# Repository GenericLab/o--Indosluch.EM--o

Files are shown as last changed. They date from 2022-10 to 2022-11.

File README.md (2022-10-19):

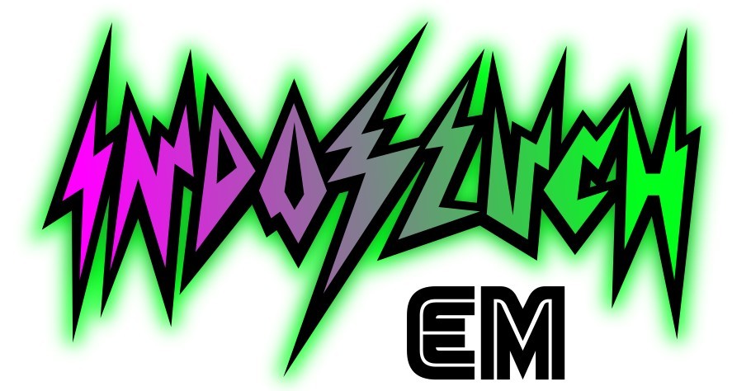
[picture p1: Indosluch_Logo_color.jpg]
IndoSluch Logo by Helmi


# o--Indosluch.EM--o
New pisibi and circuit for EM-sniffer, inspired by LOM's Elektrosluch (Error Static Zapper too), SOMA Ether, 1010 Detektor and Franzis' Bat-Detector and many others...

Goal: Make an affordable new and kinda modified / improved version of an EM sniffer in Yoygakarta, Indonesia. Use mainly parts that can be sourced locally on the common online shops or local stores.

Ideas:
* runs on 3V, LiPo, USB charging and / or powerbank
* single input / mono (mbe switched plug, to insert self-made antennas/coils)
* internal small speaker
* Volume knob
* Frequency shifting / demoluation of higher bandwidths to the audio range (with a knob to select bands)
* output mini-jack, 3.5mm
* beautifully crafted local teakwood casing
* ...

# Collaborators
* dusjagr
* Fiky
* Ucok

## Counselors
* Uwe, the Opa Master
* Ralf, another Opa Master

# Case study and mock-ups

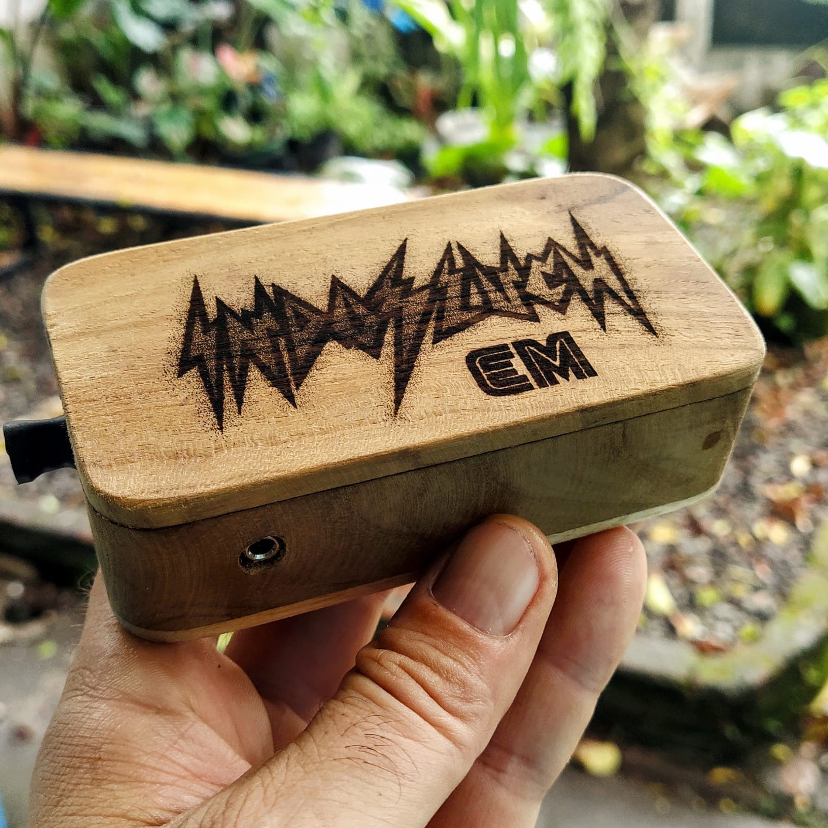
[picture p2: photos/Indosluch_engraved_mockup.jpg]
IndoSluch Logo by Helmi


# Reworking the Bat-Detector

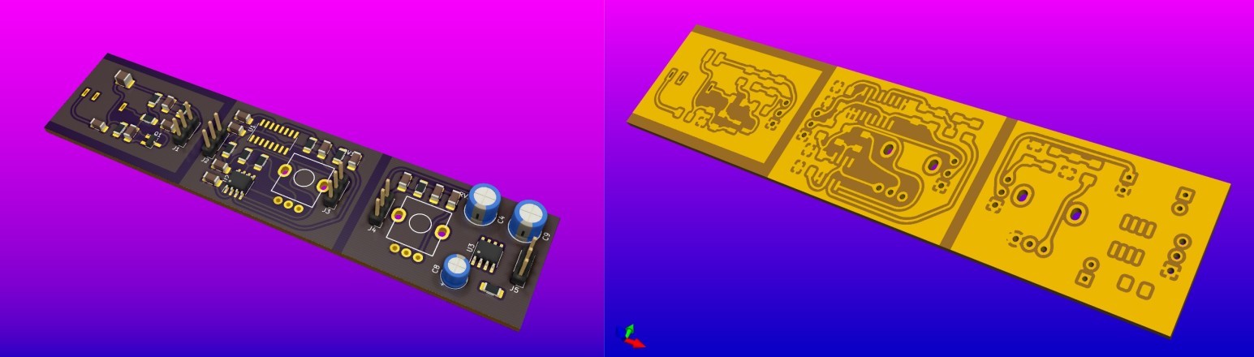
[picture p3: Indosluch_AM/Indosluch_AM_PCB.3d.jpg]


Kicad version of the Fledermaus Detektor (bat-detector): https://www.elektronik-labor.de/Lernpakete/Fledermaus.html

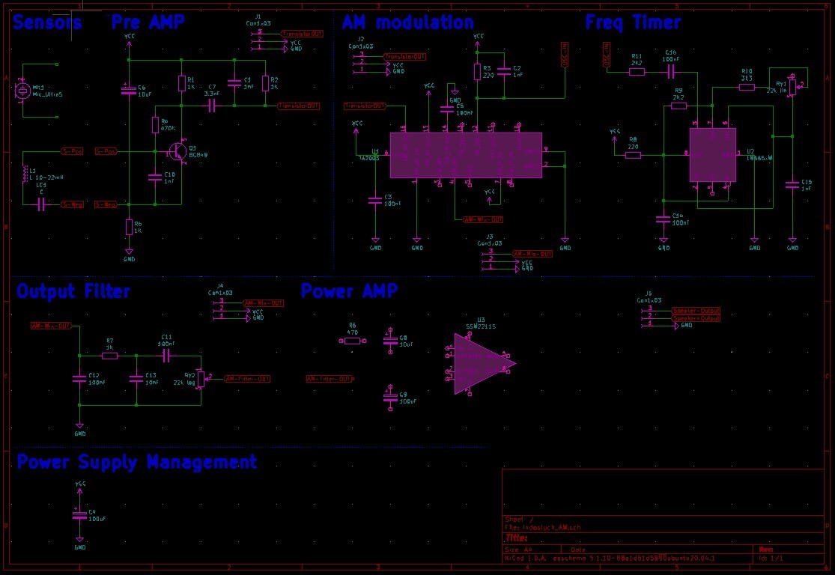
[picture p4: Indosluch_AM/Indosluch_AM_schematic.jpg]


# Inspriational Sources

## LOM's Elektrosluch (open Source)

Based on a single chip dual channel bi-polar Audio Operational Amplifier, opa1612, can be replaced by cheaper more noisier TL074  (suchas the Error Zapper). Runs on 9V. 

https://github.com/LOM-instruments/Elektrosluch-3-plus

## ERROR Zapper

Seems to be a clone, cheaper version of the Elektrosluch. No credits given :-(
Runs on 9V.

https://www.errorinstruments.com/a-60734445/new-synthe-noise-instruments-for-sale/error-zapper/#description

## SOMA Ether (everything is waves)

Based on a fist stage transistor amplification, and some kinda extra antenna on the board for higher frequency bands and a potentiomter for atenuation. Second stage with SSM2211 audio amplifier. Runs on 3V.

https://somasynths.com/ether/

## 1010 Detektor by Martin Howse (open Source)

Based on AD8313 HF-detektor (kinda expensive) and fist stage amplification with LM358, second LM386. Runs on 4.5V.

http://www.1010.co.uk/org/detektor.html

## Elektronik-Labor |  Bat-Detector (open Source) in german

Based on a first stage single transistor amplification, and a radio AM/FM chip CD2003 for high-frequency demodulation, frequency is adjusted with 555 timer. Final amplification stage with LM386. Original design runs on 9V, but lower voltage should work.

https://www.elektronik-labor.de/Lernpakete/Fledermaus.html

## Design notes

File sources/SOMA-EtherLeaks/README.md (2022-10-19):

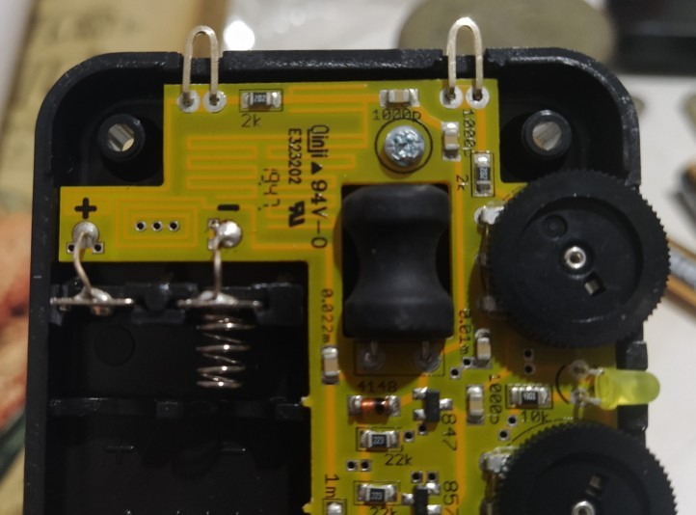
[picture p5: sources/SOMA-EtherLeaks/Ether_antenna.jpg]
Inside the SOMA Ether


# Ether-Leaks

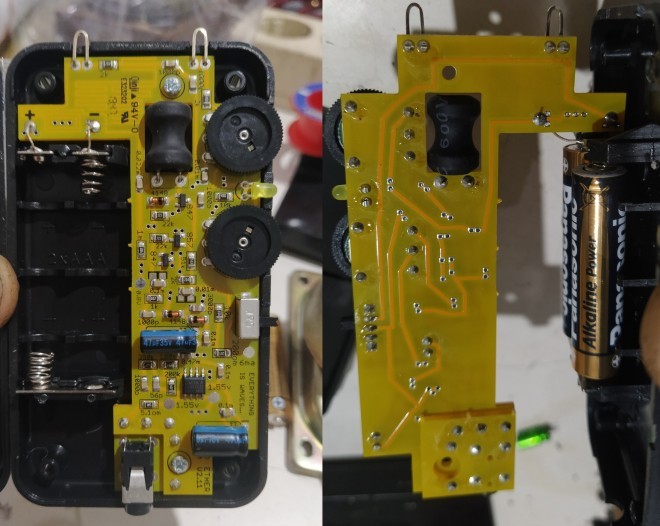
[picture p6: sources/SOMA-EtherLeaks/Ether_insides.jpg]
Inside the SOMA Ether


## SOMA Ether (everything is waves)

Based on a fist stage transistor amplification, and some kinda extra antenna on the board for higher frequency bands and a potentiomter for atenuation. Second stage with SSM2211 audio amplifier. Runs on 3V.

https://somasynths.com/ether/

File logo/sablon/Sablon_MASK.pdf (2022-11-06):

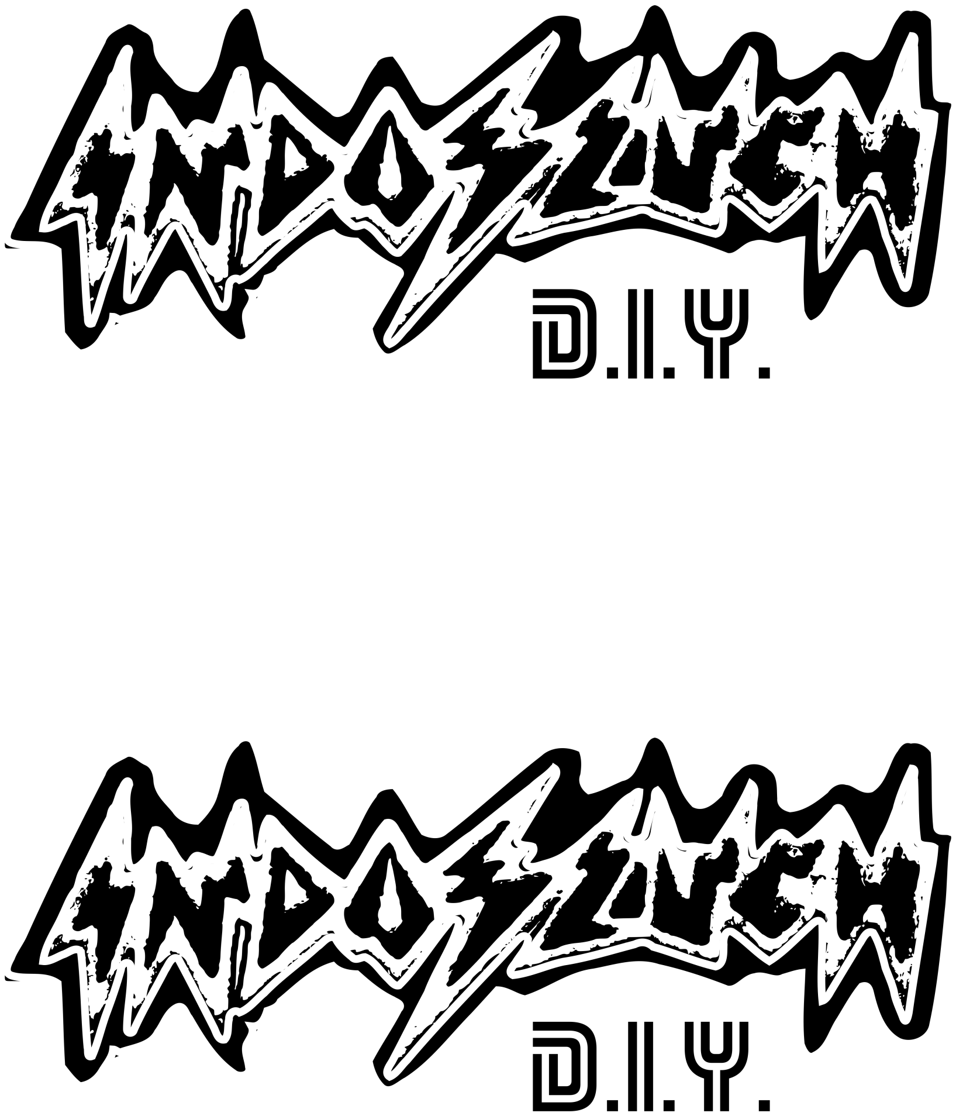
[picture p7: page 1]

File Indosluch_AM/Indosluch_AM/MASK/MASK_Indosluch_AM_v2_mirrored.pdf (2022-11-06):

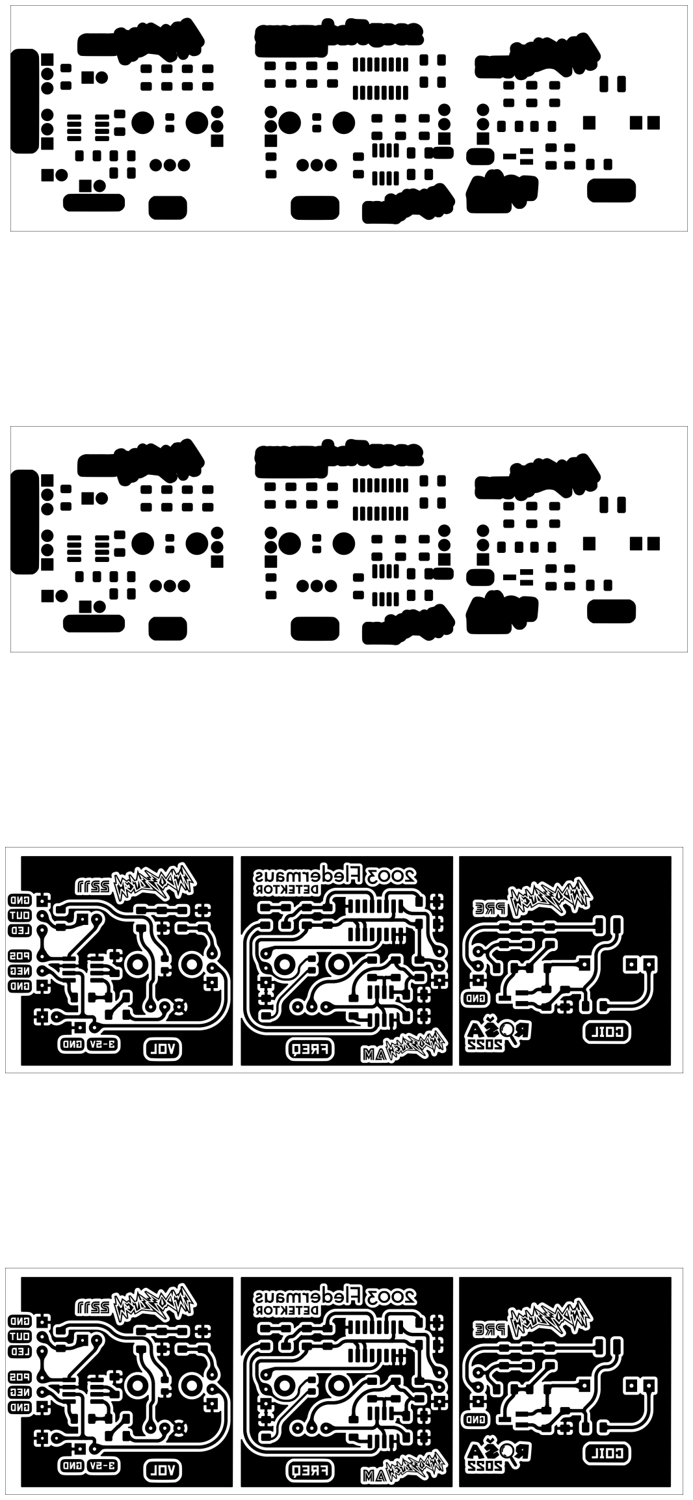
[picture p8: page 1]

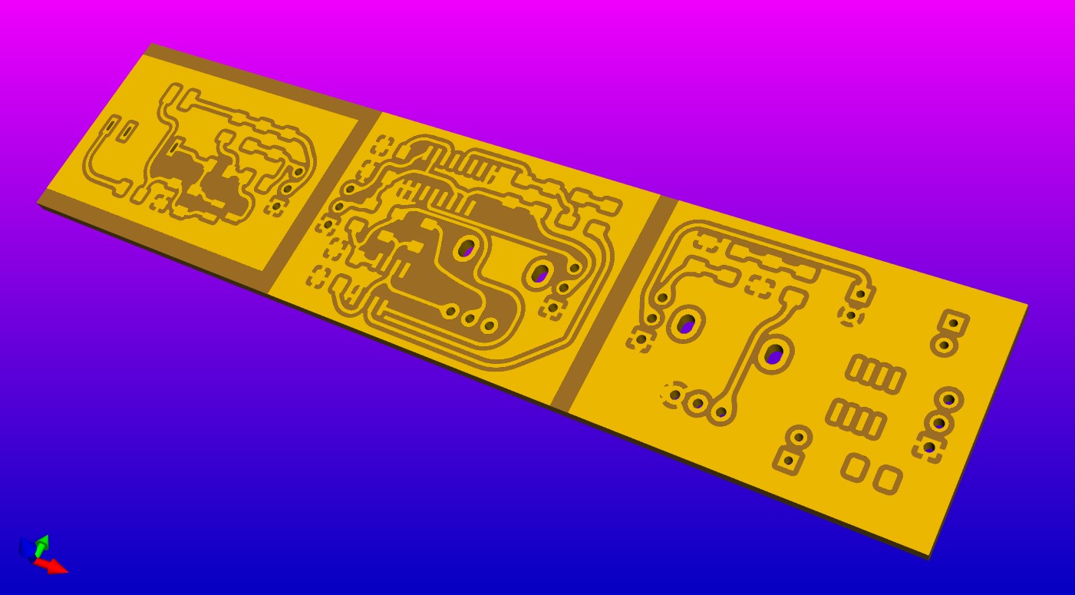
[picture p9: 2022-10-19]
photos/Indosluch_AM_copper.jpg

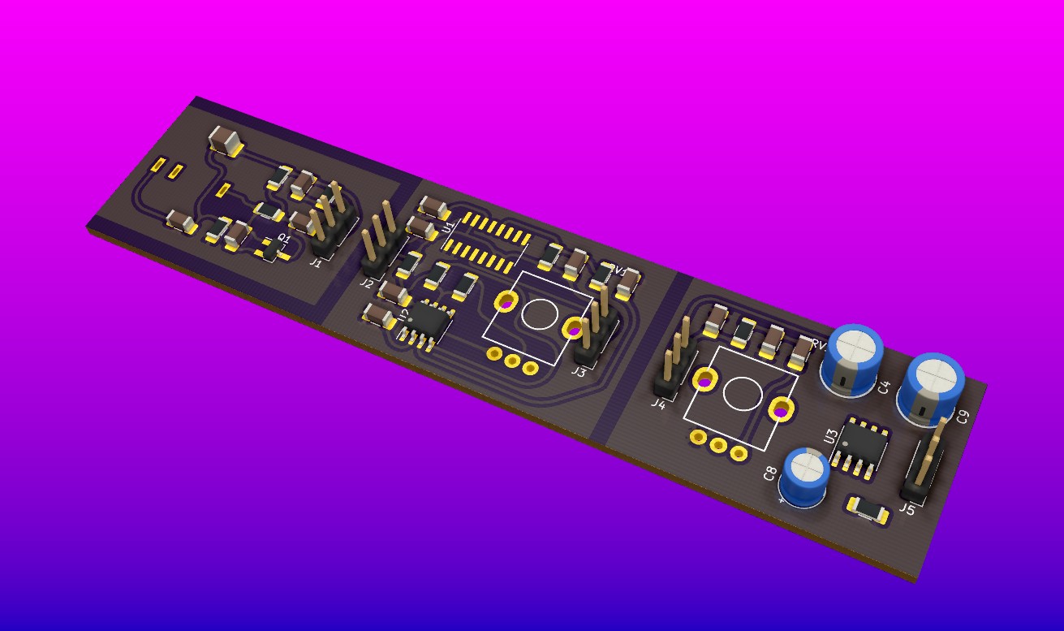
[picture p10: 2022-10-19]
photos/Indosluch_AM_3D.jpg

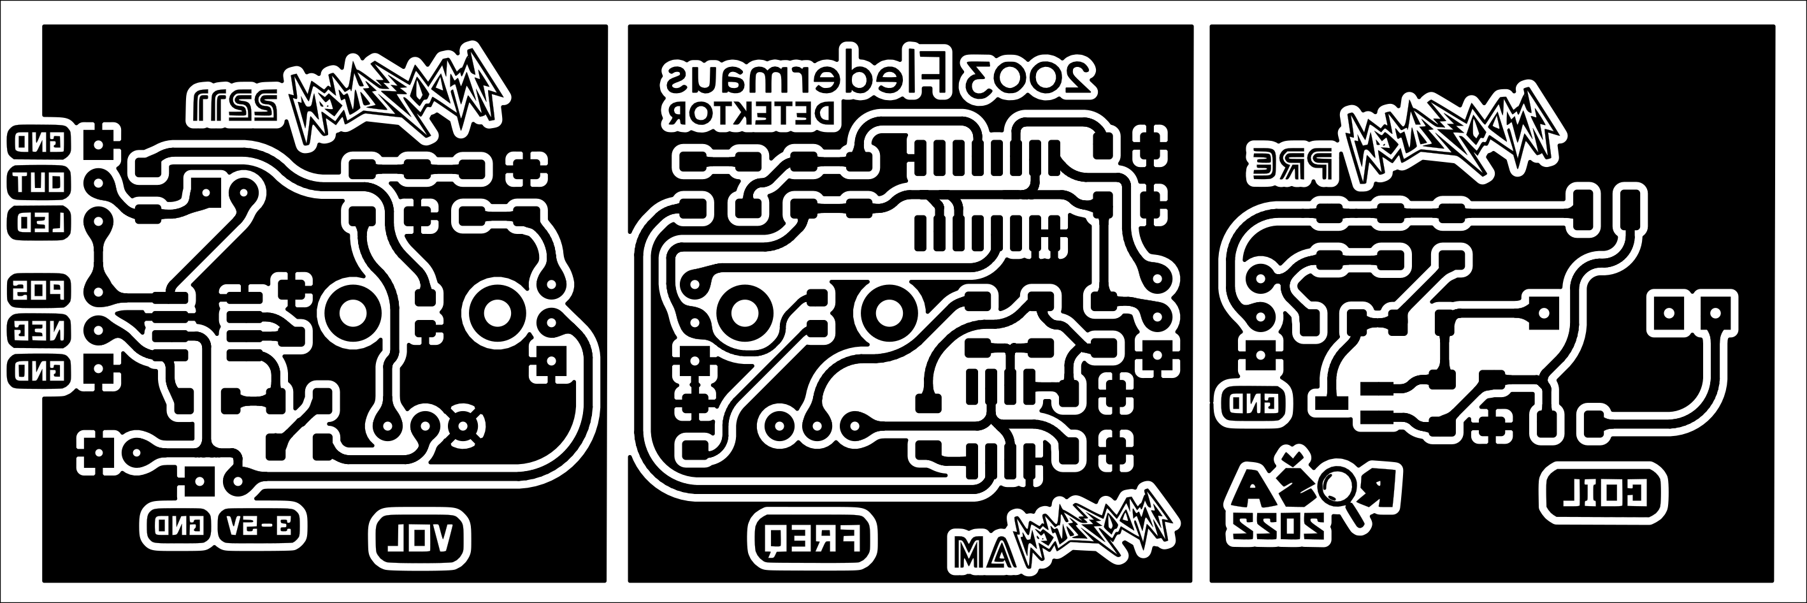
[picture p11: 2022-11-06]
Indosluch_AM/Indosluch_AM/MASK/FrontMask.png

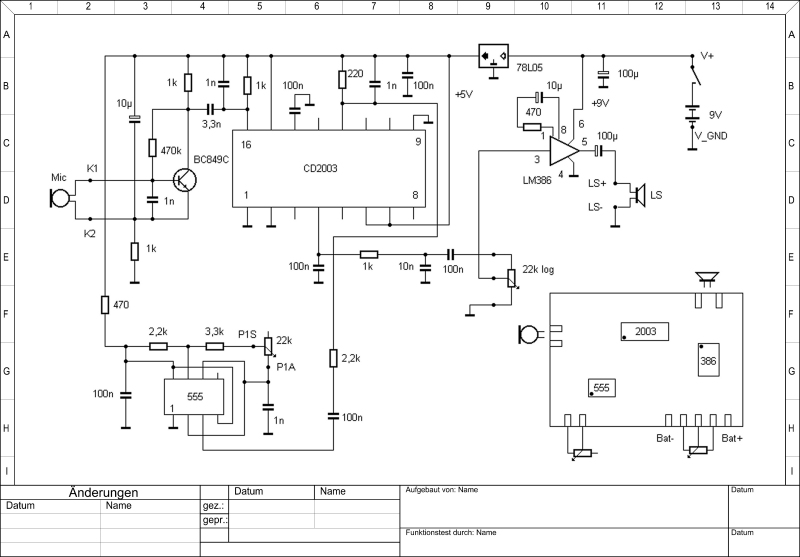
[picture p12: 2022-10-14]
sources/Franzis_Bat-Detector/CD2003_Bat-Detector.jpg

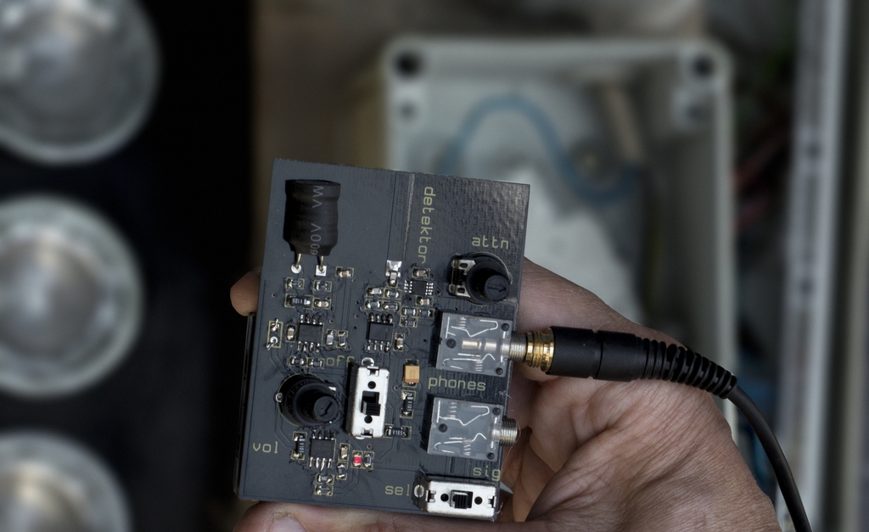
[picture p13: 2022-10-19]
sources/MartinHowse_Detektor/Detektor_finalBoard.jpg

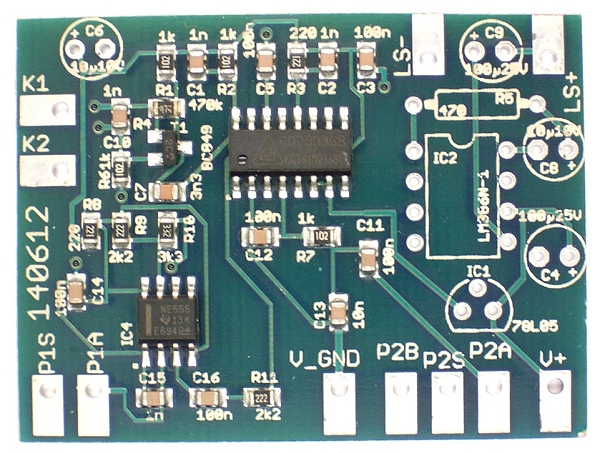
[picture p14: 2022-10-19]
sources/Franzis_Bat-Detector/Fledermaus_PCB.jpg

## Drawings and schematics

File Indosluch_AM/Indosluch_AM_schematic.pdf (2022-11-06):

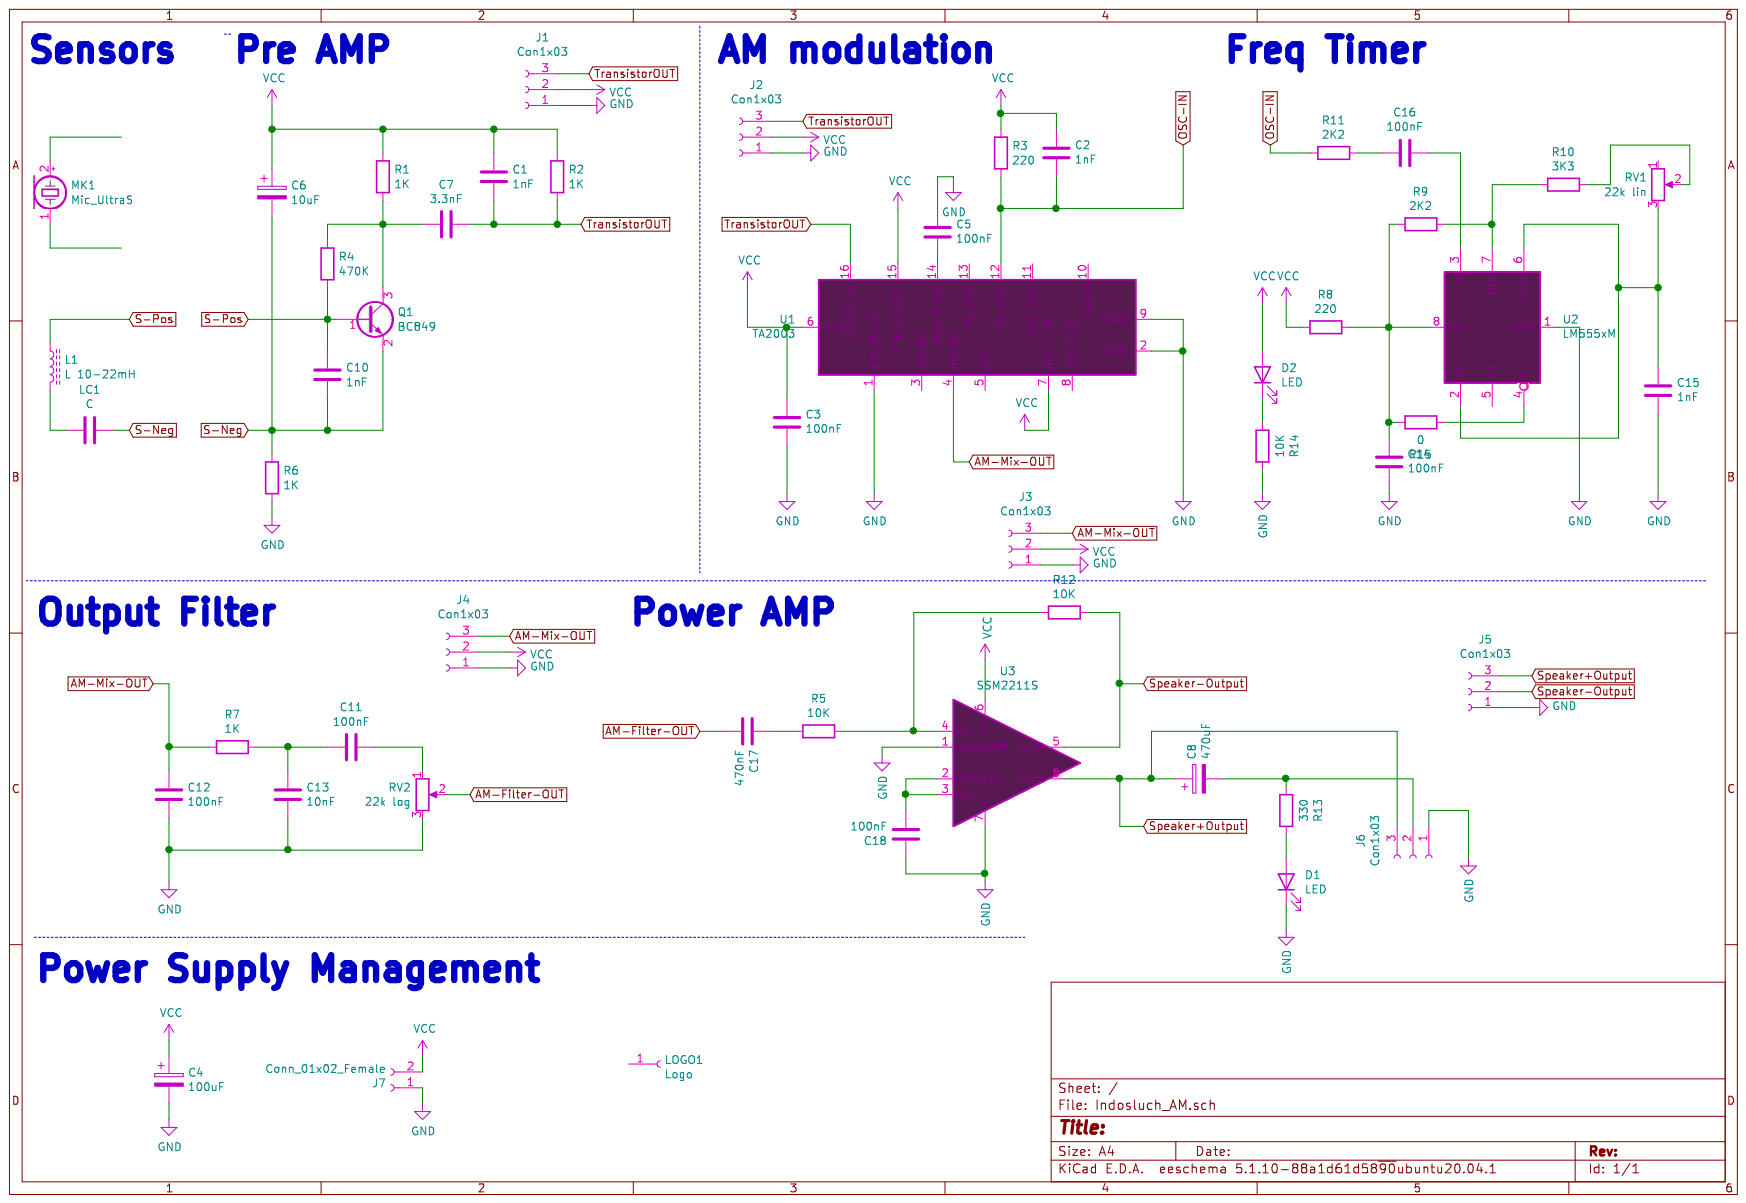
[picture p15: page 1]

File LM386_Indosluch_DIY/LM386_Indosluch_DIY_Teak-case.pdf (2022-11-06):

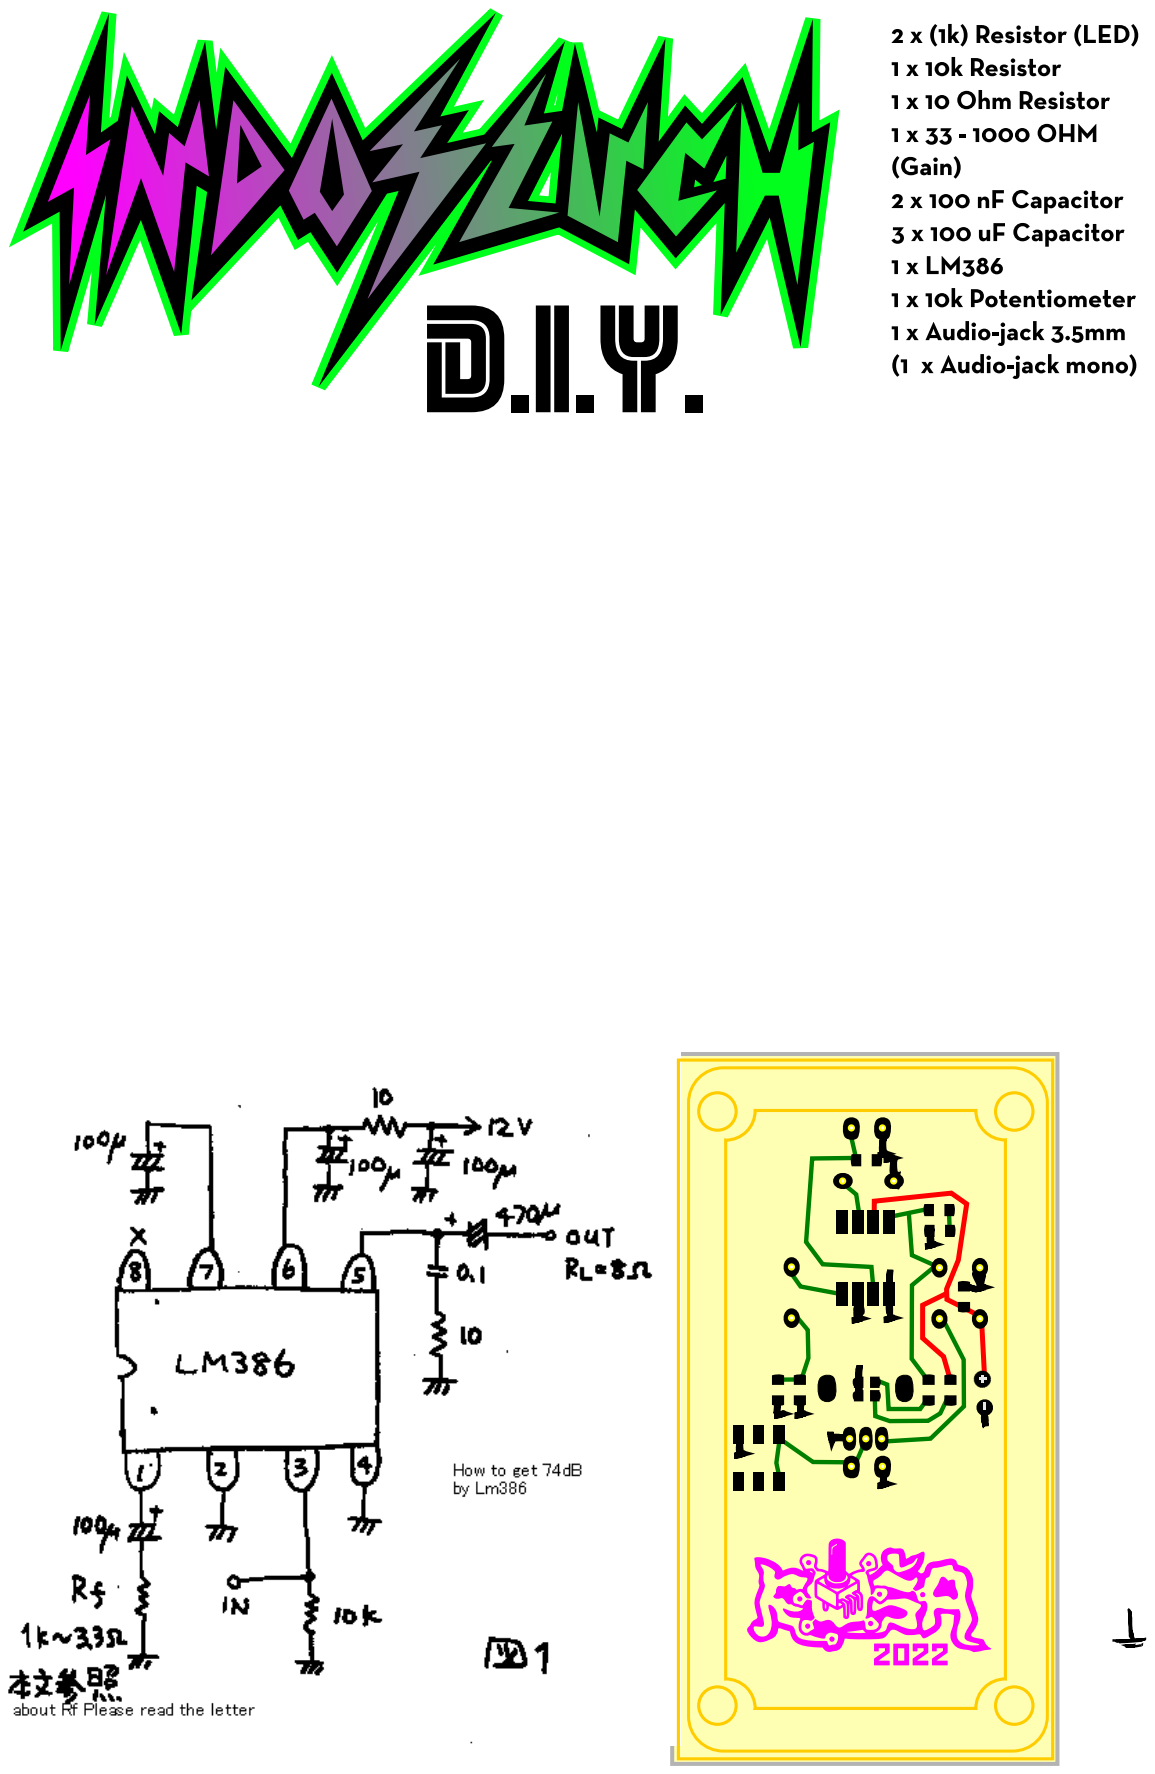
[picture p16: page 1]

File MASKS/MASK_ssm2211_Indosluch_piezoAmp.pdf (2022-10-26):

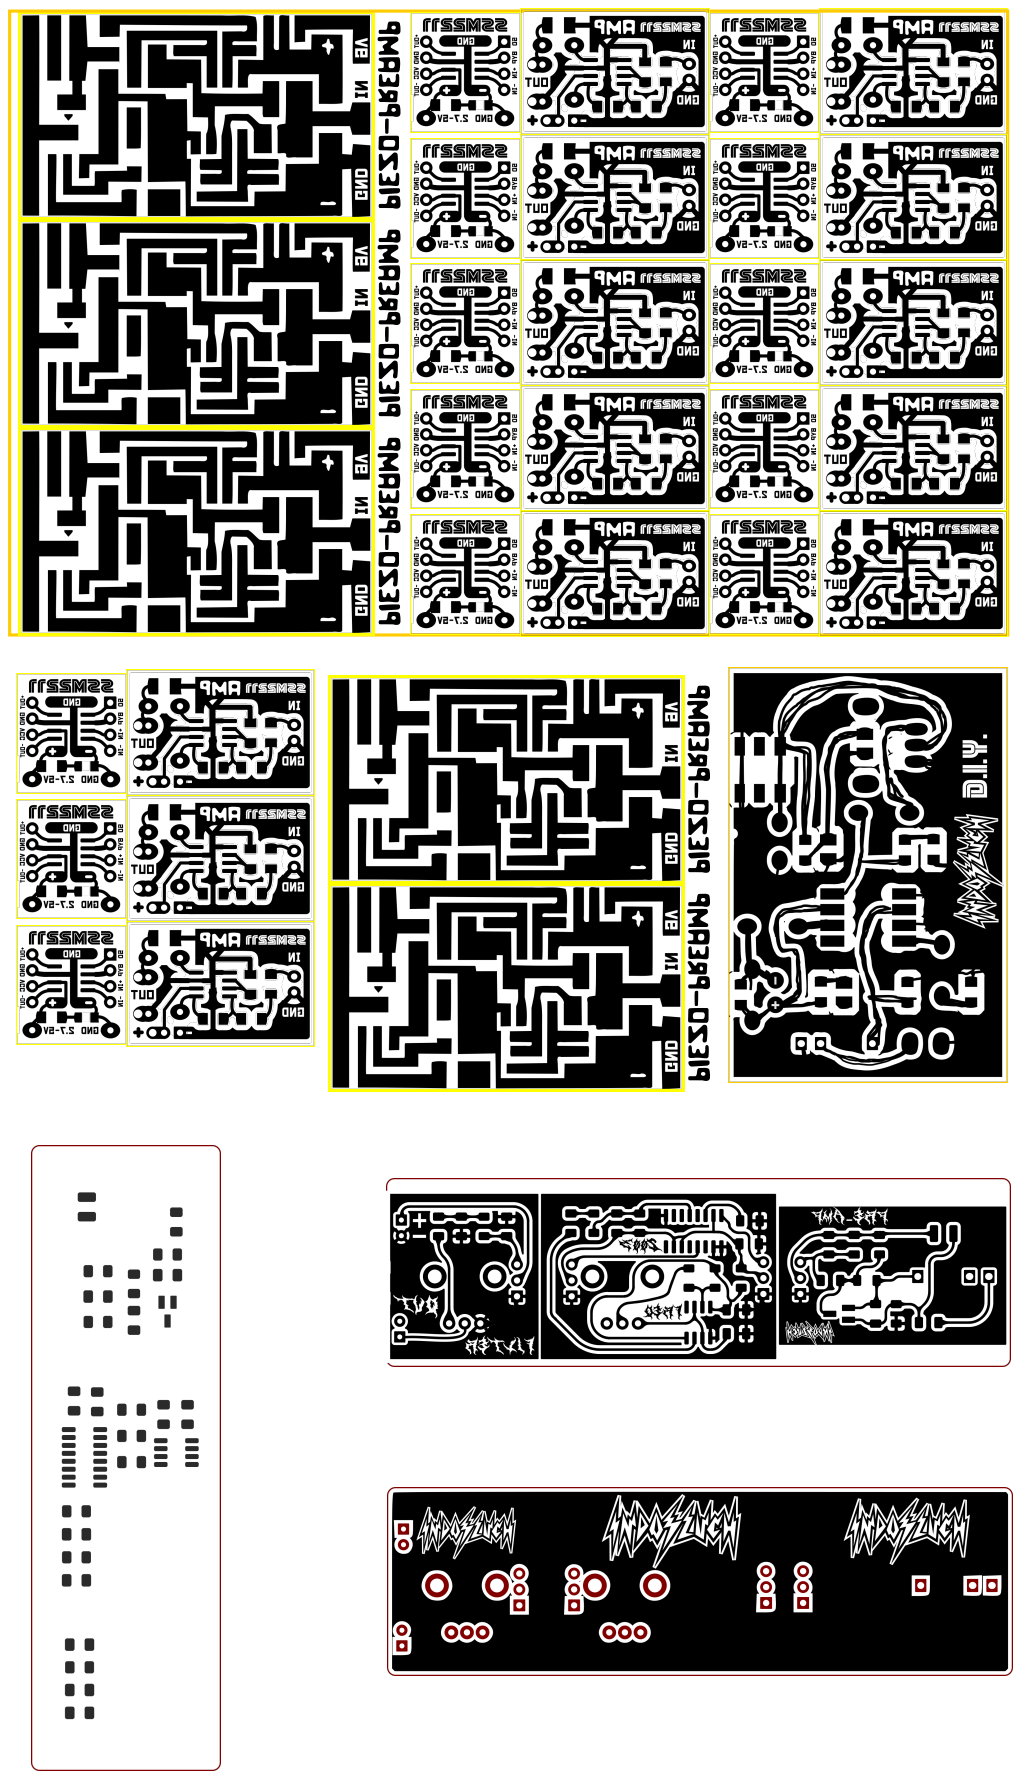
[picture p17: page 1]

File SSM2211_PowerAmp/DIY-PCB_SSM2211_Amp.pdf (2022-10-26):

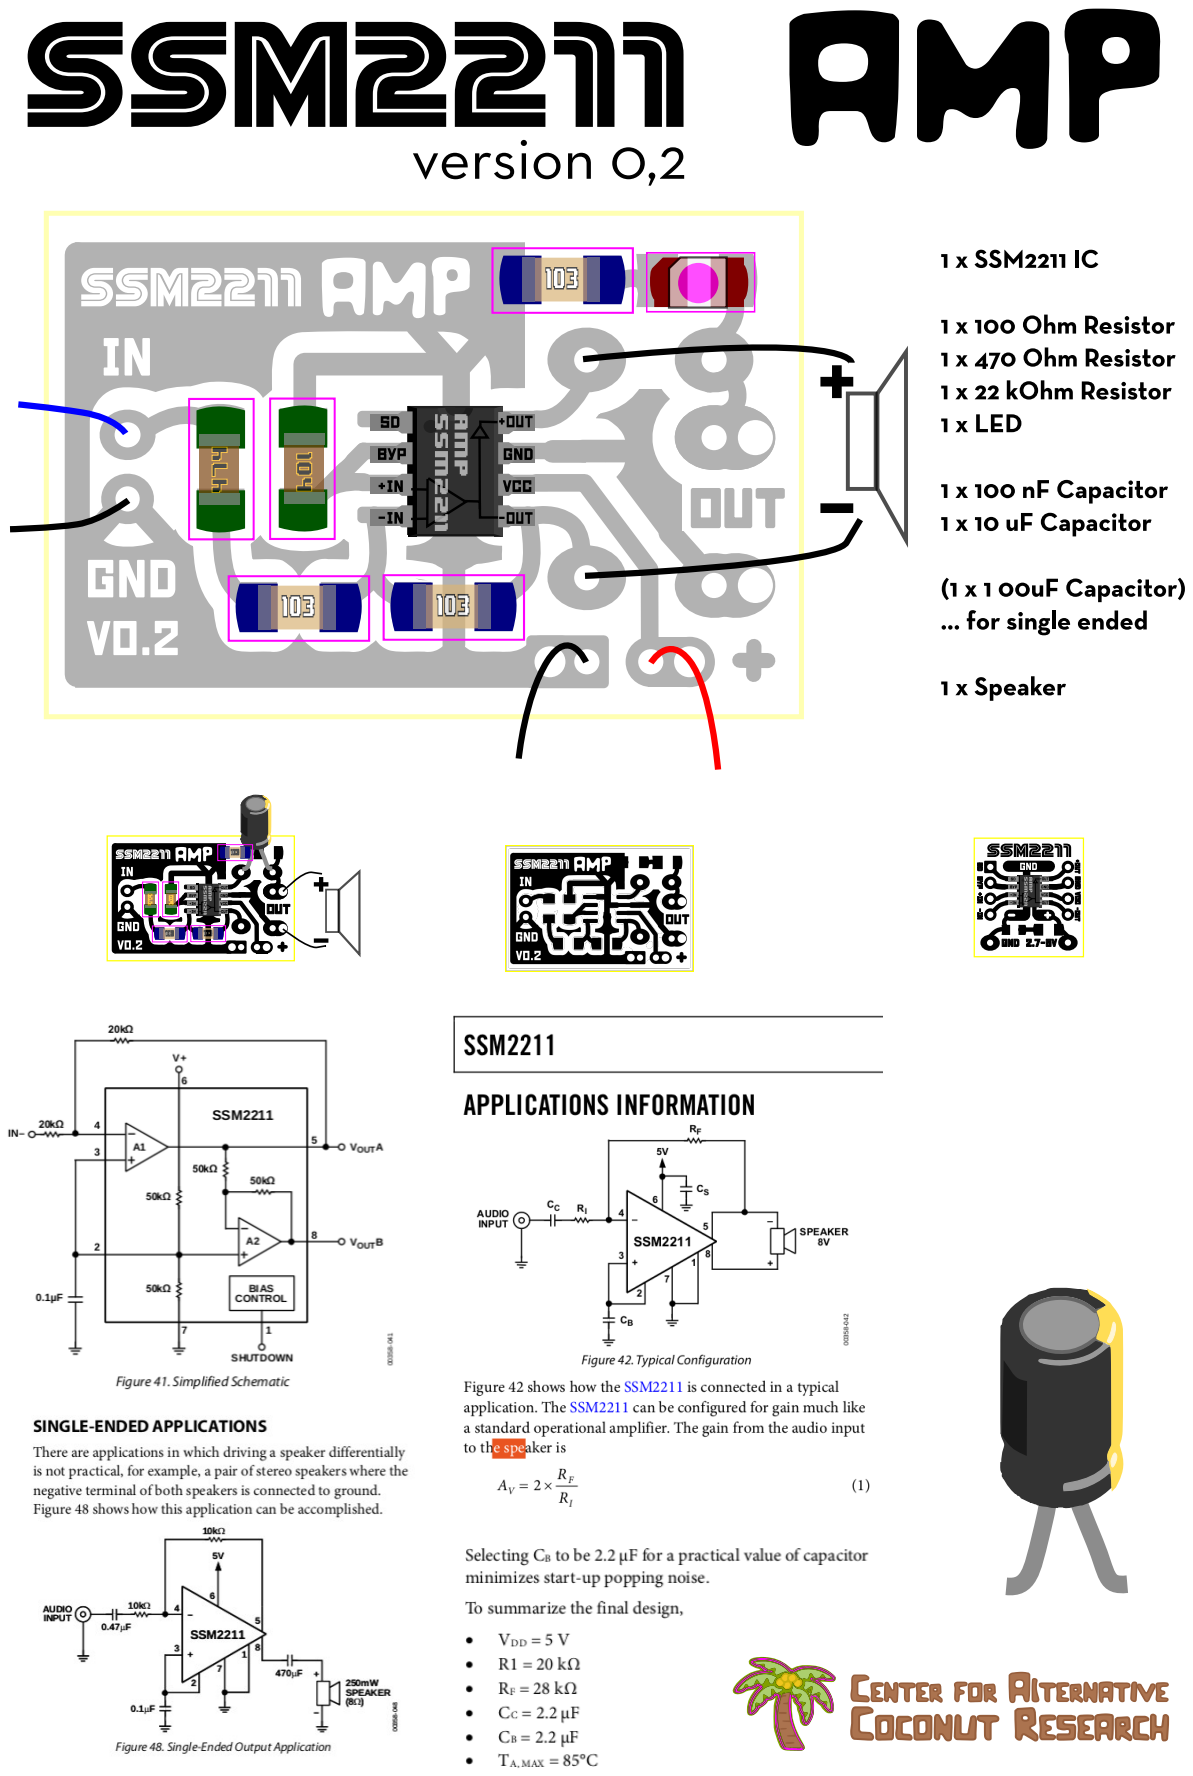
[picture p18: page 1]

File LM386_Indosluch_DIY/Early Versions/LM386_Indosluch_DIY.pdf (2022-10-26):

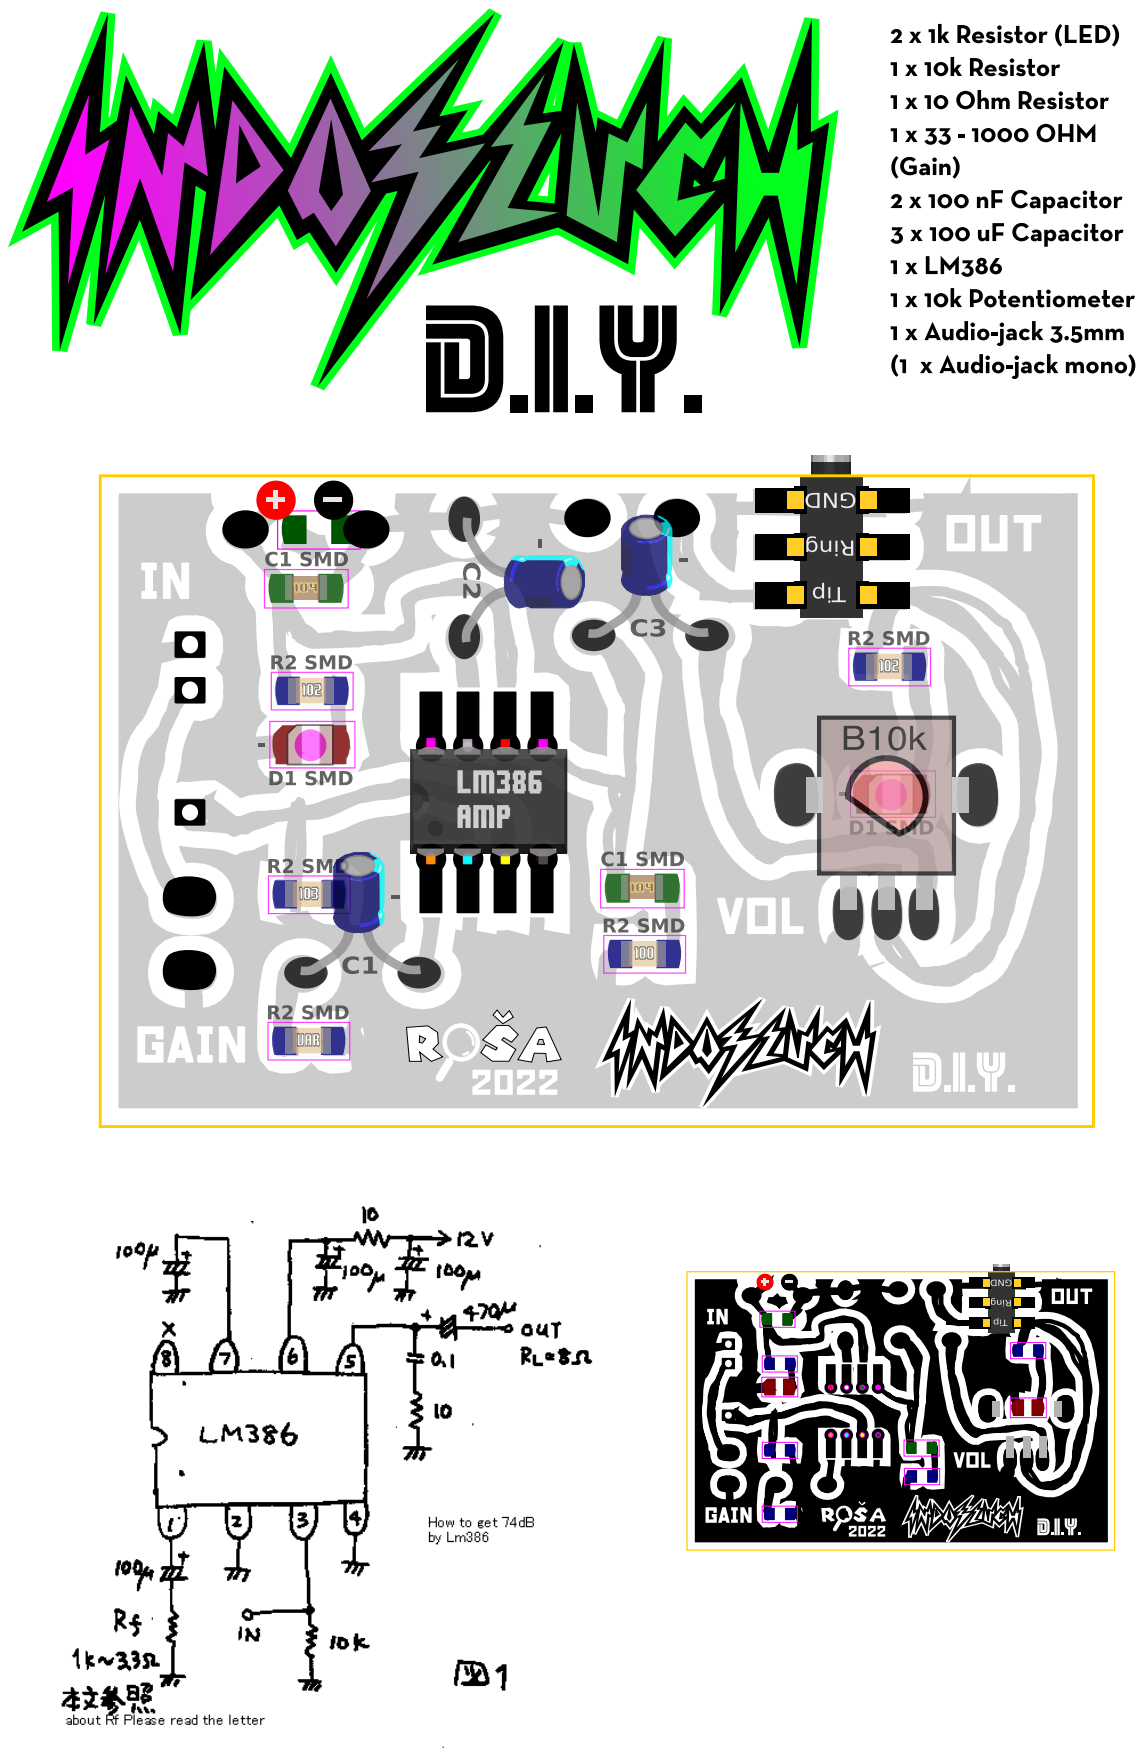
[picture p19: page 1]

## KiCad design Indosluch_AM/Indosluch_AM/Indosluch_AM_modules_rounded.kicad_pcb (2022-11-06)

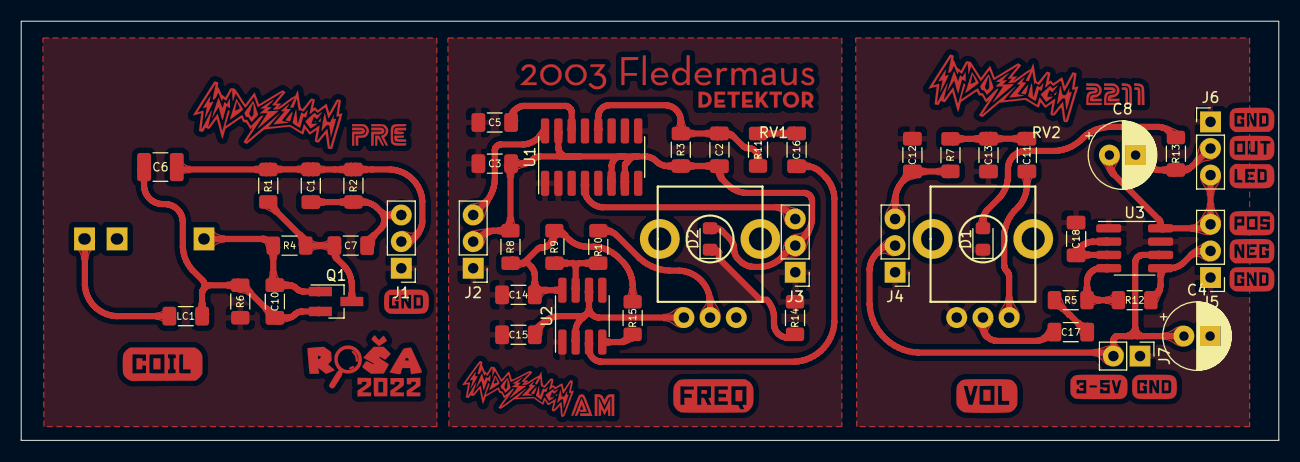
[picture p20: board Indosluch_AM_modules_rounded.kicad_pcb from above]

Board: 2 copper layers, 120.0 x 40.0 mm, 50 parts (0 on the bottom side), 28 nets.

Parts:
C1, C2, C10, C15: 1nF; C_1206_dusjagr
C3, C5, C11, C12, C14, C16, C18: 100nF; C_1206_dusjagr
C4: 100uF; Capacitor_Radial_D6.3mm_P2.50mm
C6: 10uF; C_1210_dusjagr
C7: 3.3nF; C_1206_dusjagr
C8: 470uF; Capacitor_Radial_D6.3mm_P2.50mm
C13: 10nF; C_1206_dusjagr
C17: 470nF; C_1206_dusjagr
D1, D2: LED; LED_0805_2012Metric_Pad1.15x1.40mm_HandSolder
J1, J2, J3, J4, J5, J6: Con1x03; PinHeader_1x03_HandSolder
J7: Conn_01x02_Female; PinHeader_1x02_P2.54mm_HandSolder
L1: L 10-22mH; PJ301M-12_dusjagr_handSolder
LC1: C; C_1206_dusjagr
LOGO1: Logo; Indosluch_logos
Q1: BC849; SOT-23_Handsoldering
R1, R2, R6, R7: 1K; R_1206_dusjagr
R3, R8: 220; R_1206_dusjagr
R4: 470K; R_1206_dusjagr
R5, R12, R14: 10K; R_1206_dusjagr
R9, R11: 2K2; R_1206_dusjagr
R10: 3K3; R_1206_dusjagr
R13: 330; R_1206_dusjagr
R15: 0; R_1206_dusjagr
RV1: 22k lin; RD901F-ALPHA-HandSolder
RV2: 22k log; RD901F-ALPHA-HandSolder
U1: TA2003; SOP-16_HandSolder
U2: LM555xM; SOIC-8_HandSolder
U3: SSM2211S; SOIC-8_HandSolder

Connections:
AM-Filter-OUT: C17.2, RV2.2
AM-Mix-OUT: C12.1, J3.3, J4.3, R7.2, U1.4
GND: C3.1, C4.2, C5.2, C12.2, C13.2, C14.1, C15.1, C18.1, D1.1, J1.1, J2.1, J3.1, J4.1, J5.1, J6.1, J7.1, R6.2, R14.1, RV2.3, U1.1, U1.2, U1.9, U2.1, U3.1, U3.7
unnamed: C5.1, U1.14
unnamed: C7.2, Q1.3, R1.2, R4.1
unnamed: C8.2, J6.2, R13.2
unnamed: C11.1, RV2.1
unnamed: C11.2, C13.1, R7.1
unnamed: C14.2, R8.1, R9.2, R15.1, U2.8
unnamed: C15.2, RV1.3, U2.2, U2.6
unnamed: C16.1, R11.1
unnamed: C16.2, U2.3
unnamed: C17.1, R5.2
unnamed: C18.2, U3.2, U3.3
unnamed: D1.2, R13.1
unnamed: D2.1, R14.2
unnamed: L1.2, LC1.1
unnamed: R10.1, RV1.2
unnamed: R9.1, R10.2, U2.7
unnamed: R5.1, R12.2, U3.4
unnamed: R15.2, U2.4
OSC-IN: C2.1, R3.2, R11.2, U1.12
S-Neg: C6.2, C10.2, LC1.2, Q1.2, R6.1
S-Pos: C10.1, L1.1, Q1.1, R4.2
Speaker+Output: C8.1, J5.3, J6.3, U3.8
Speaker-Output: J5.2, R12.1, U3.5
TransistorOUT: C1.2, C7.1, J1.3, J2.3, R2.2, U1.16
VCC: C1.1, C2.2, C3.2, C4.1, C6.1, D2.2, J1.2, J2.2, J3.2, J4.2, J7.2, R1.1, R2.1, R3.1, R8.2, U1.6, U1.7, U1.15, U3.6

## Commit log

2022-10-19 kicad version of bat-detector
    [Indosluch_AM.kicad_pcb, Indosluch_AM.sch, Indosluch_AM_modules.kicad_pcb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]
2022-10-26 new DIY version
    [Indosluch_AM_modules_round.kicad_pcb]
2022-11-06 new DIY versions
    [Indosluch_AM.sch, Indosluch_AM_modules.kicad_pcb, Indosluch_AM_modules_bak.kicad_pcb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]
